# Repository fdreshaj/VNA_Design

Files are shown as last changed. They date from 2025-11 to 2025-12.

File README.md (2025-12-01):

# VNA_Design
Work in Progress Design of a VNA 

The Subsystems and Simulations folder contains all files related to the research and pre fabrication testing/simulations of subsystems

VNA_Project folder contains all KiCad files of the board itself. Specifically open VNA_Project.kicad_pro to check out the design. KiCad files do not have RF subsystem layout as that will be done in ADS during testing.

Motherboard Layout

Stackup:



3D+Layer View:

















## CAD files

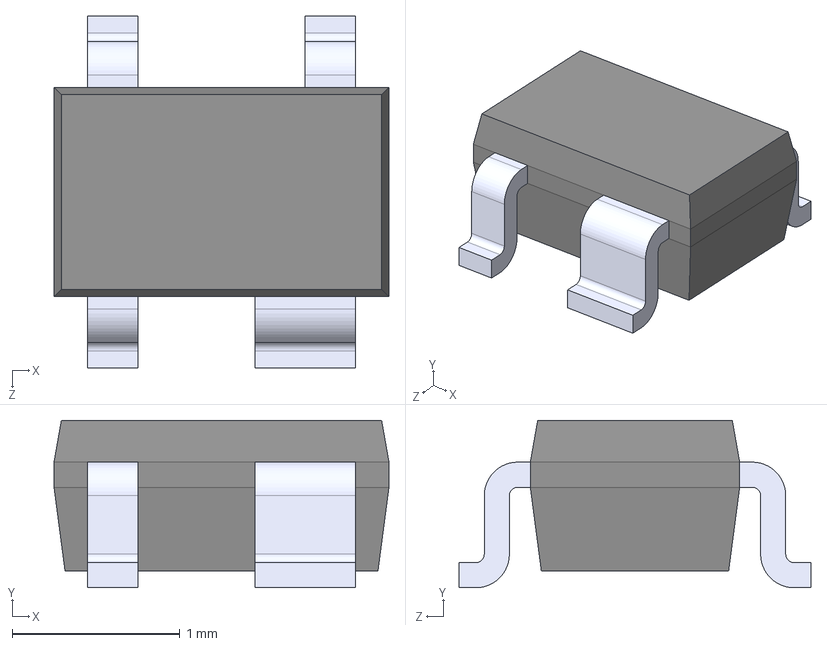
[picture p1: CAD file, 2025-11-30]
KiCad Symbols and Footprints/BFP620H7764XTSA1/BFP620H7764XTSA1.step
2.00 x 1.00 x 2.10 mm

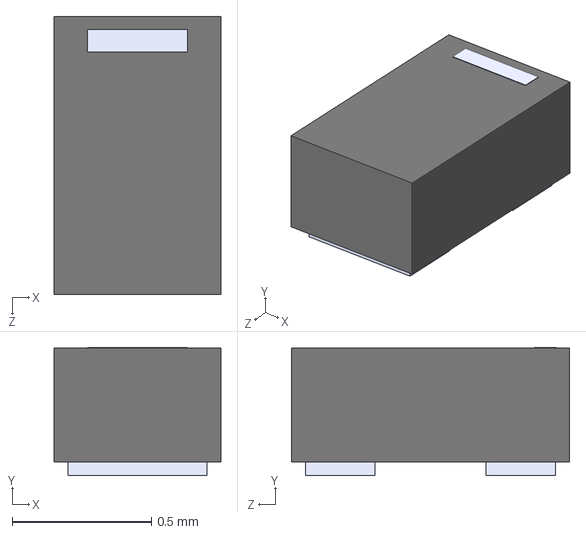
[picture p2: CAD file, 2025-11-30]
KiCad Symbols and Footprints/LIB_SMV1247-040LF/SMV1247-040LF/3D/SMV1247-040LF.stp
0.6 x 0.462 x 1.00 mm

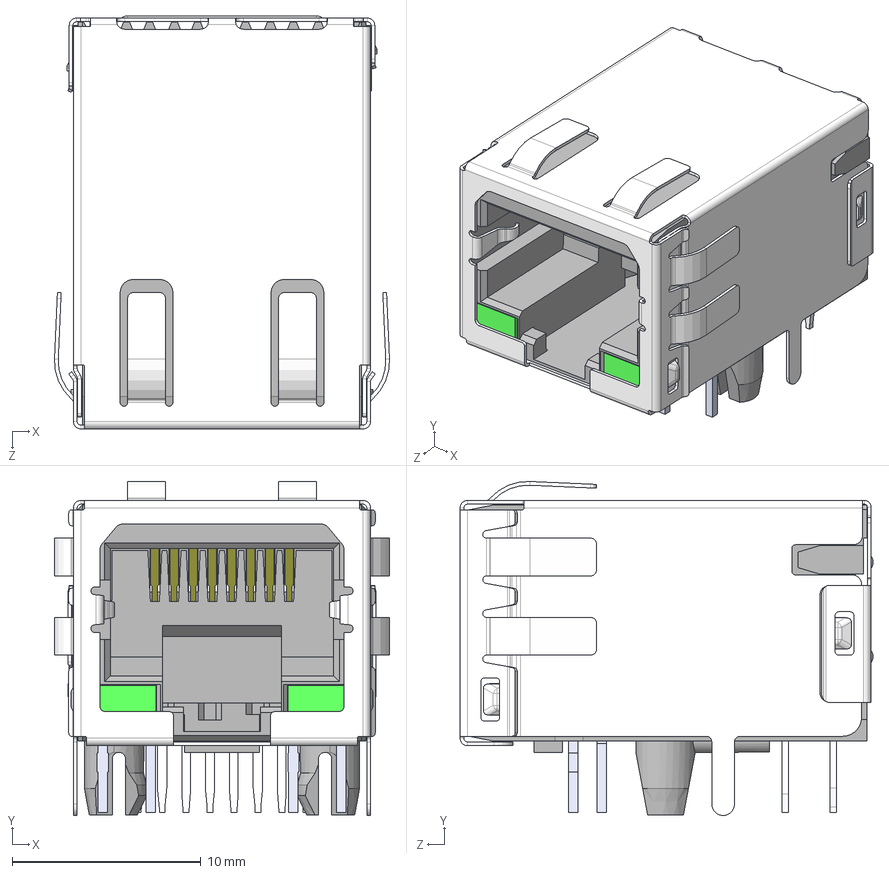
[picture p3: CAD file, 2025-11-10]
KiCad Symbols and Footprints/RJMG1BD3B8K1ANR.STEP
17.8 x 17.7 x 21.9 mm
R12-P120_C TYPE S11改善成本
R12-C130_成品 x 4
R12-C120_成品 x 4
R12-P110_R12-P110XACG-TYPE G 改善成本 斜腳燈，有鐵殼，LOCK腳
LED_LEFTｱﾗ_ x 2
R12-C310-2.20_成品
PCB_無鐵殼1G
S11-S110_ALL Spring1.0,R3.05,有燈，UDE LOGO

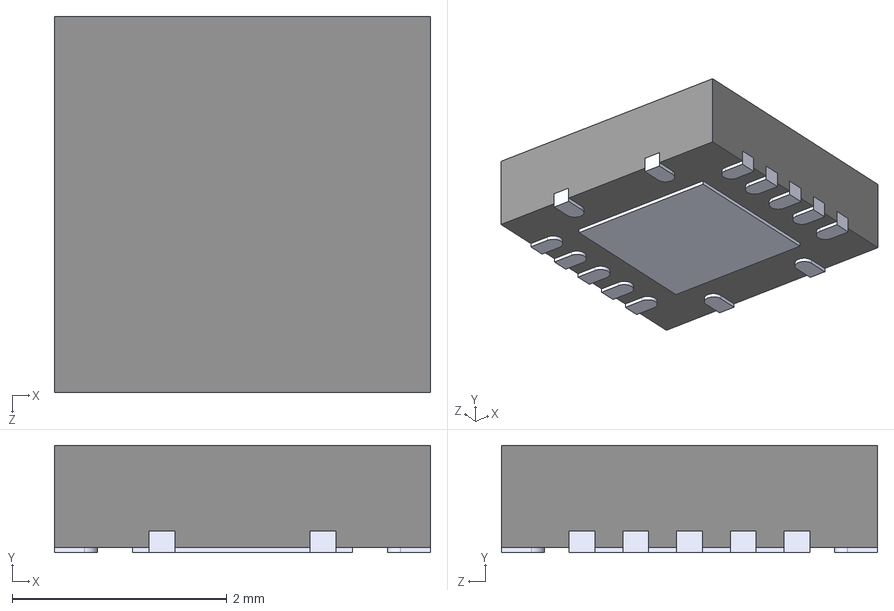
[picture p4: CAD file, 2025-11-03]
KiCad Symbols and Footprints/TPS54620RGYR/TPS54620RGYR.step
3.50 x 1.00 x 3.50 mm

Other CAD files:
KiCad Symbols and Footprints/LIB_SMV1247-040LF/SMV1247-040LF/Allegro/sms7630040lf.psm
KiCad Symbols and Footprints/LIB_SMV1247-040LF/SMV1247-040LF/DEHDL/smv1247_040lf/chips/chips.prt

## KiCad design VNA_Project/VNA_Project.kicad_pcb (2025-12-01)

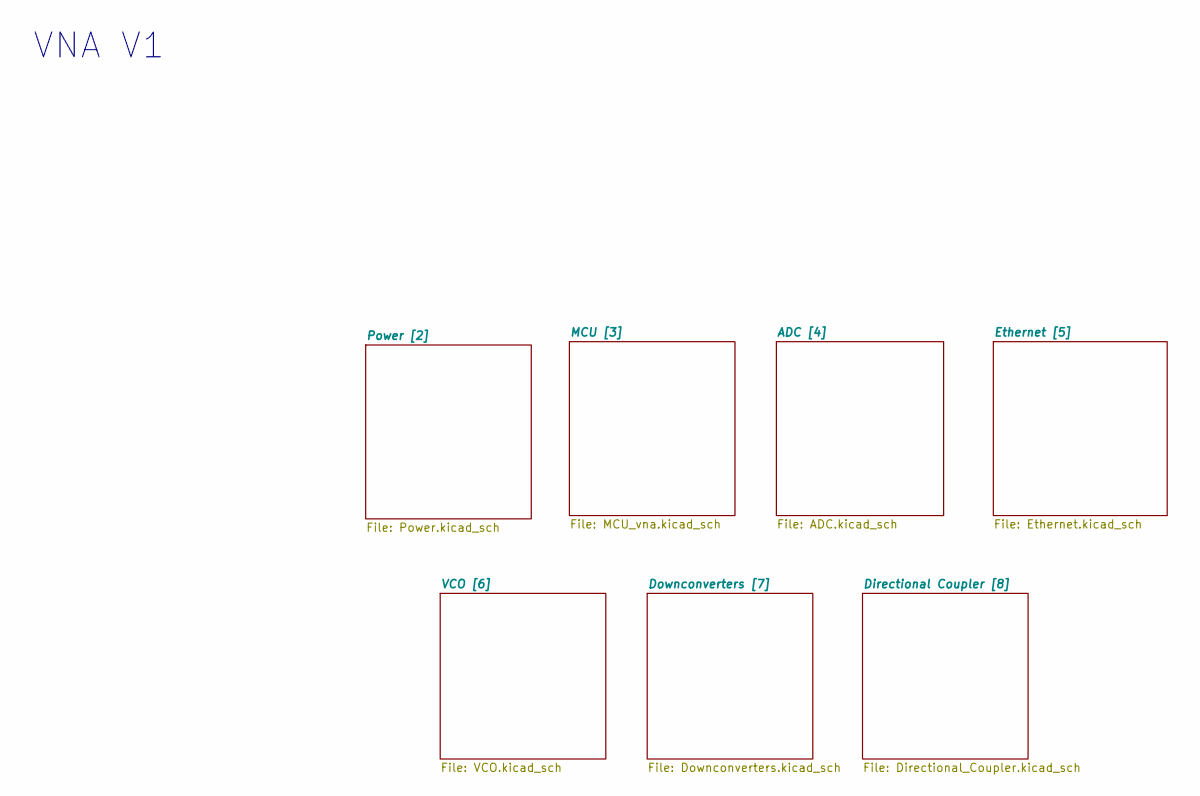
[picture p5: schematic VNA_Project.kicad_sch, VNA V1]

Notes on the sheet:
VNA V1

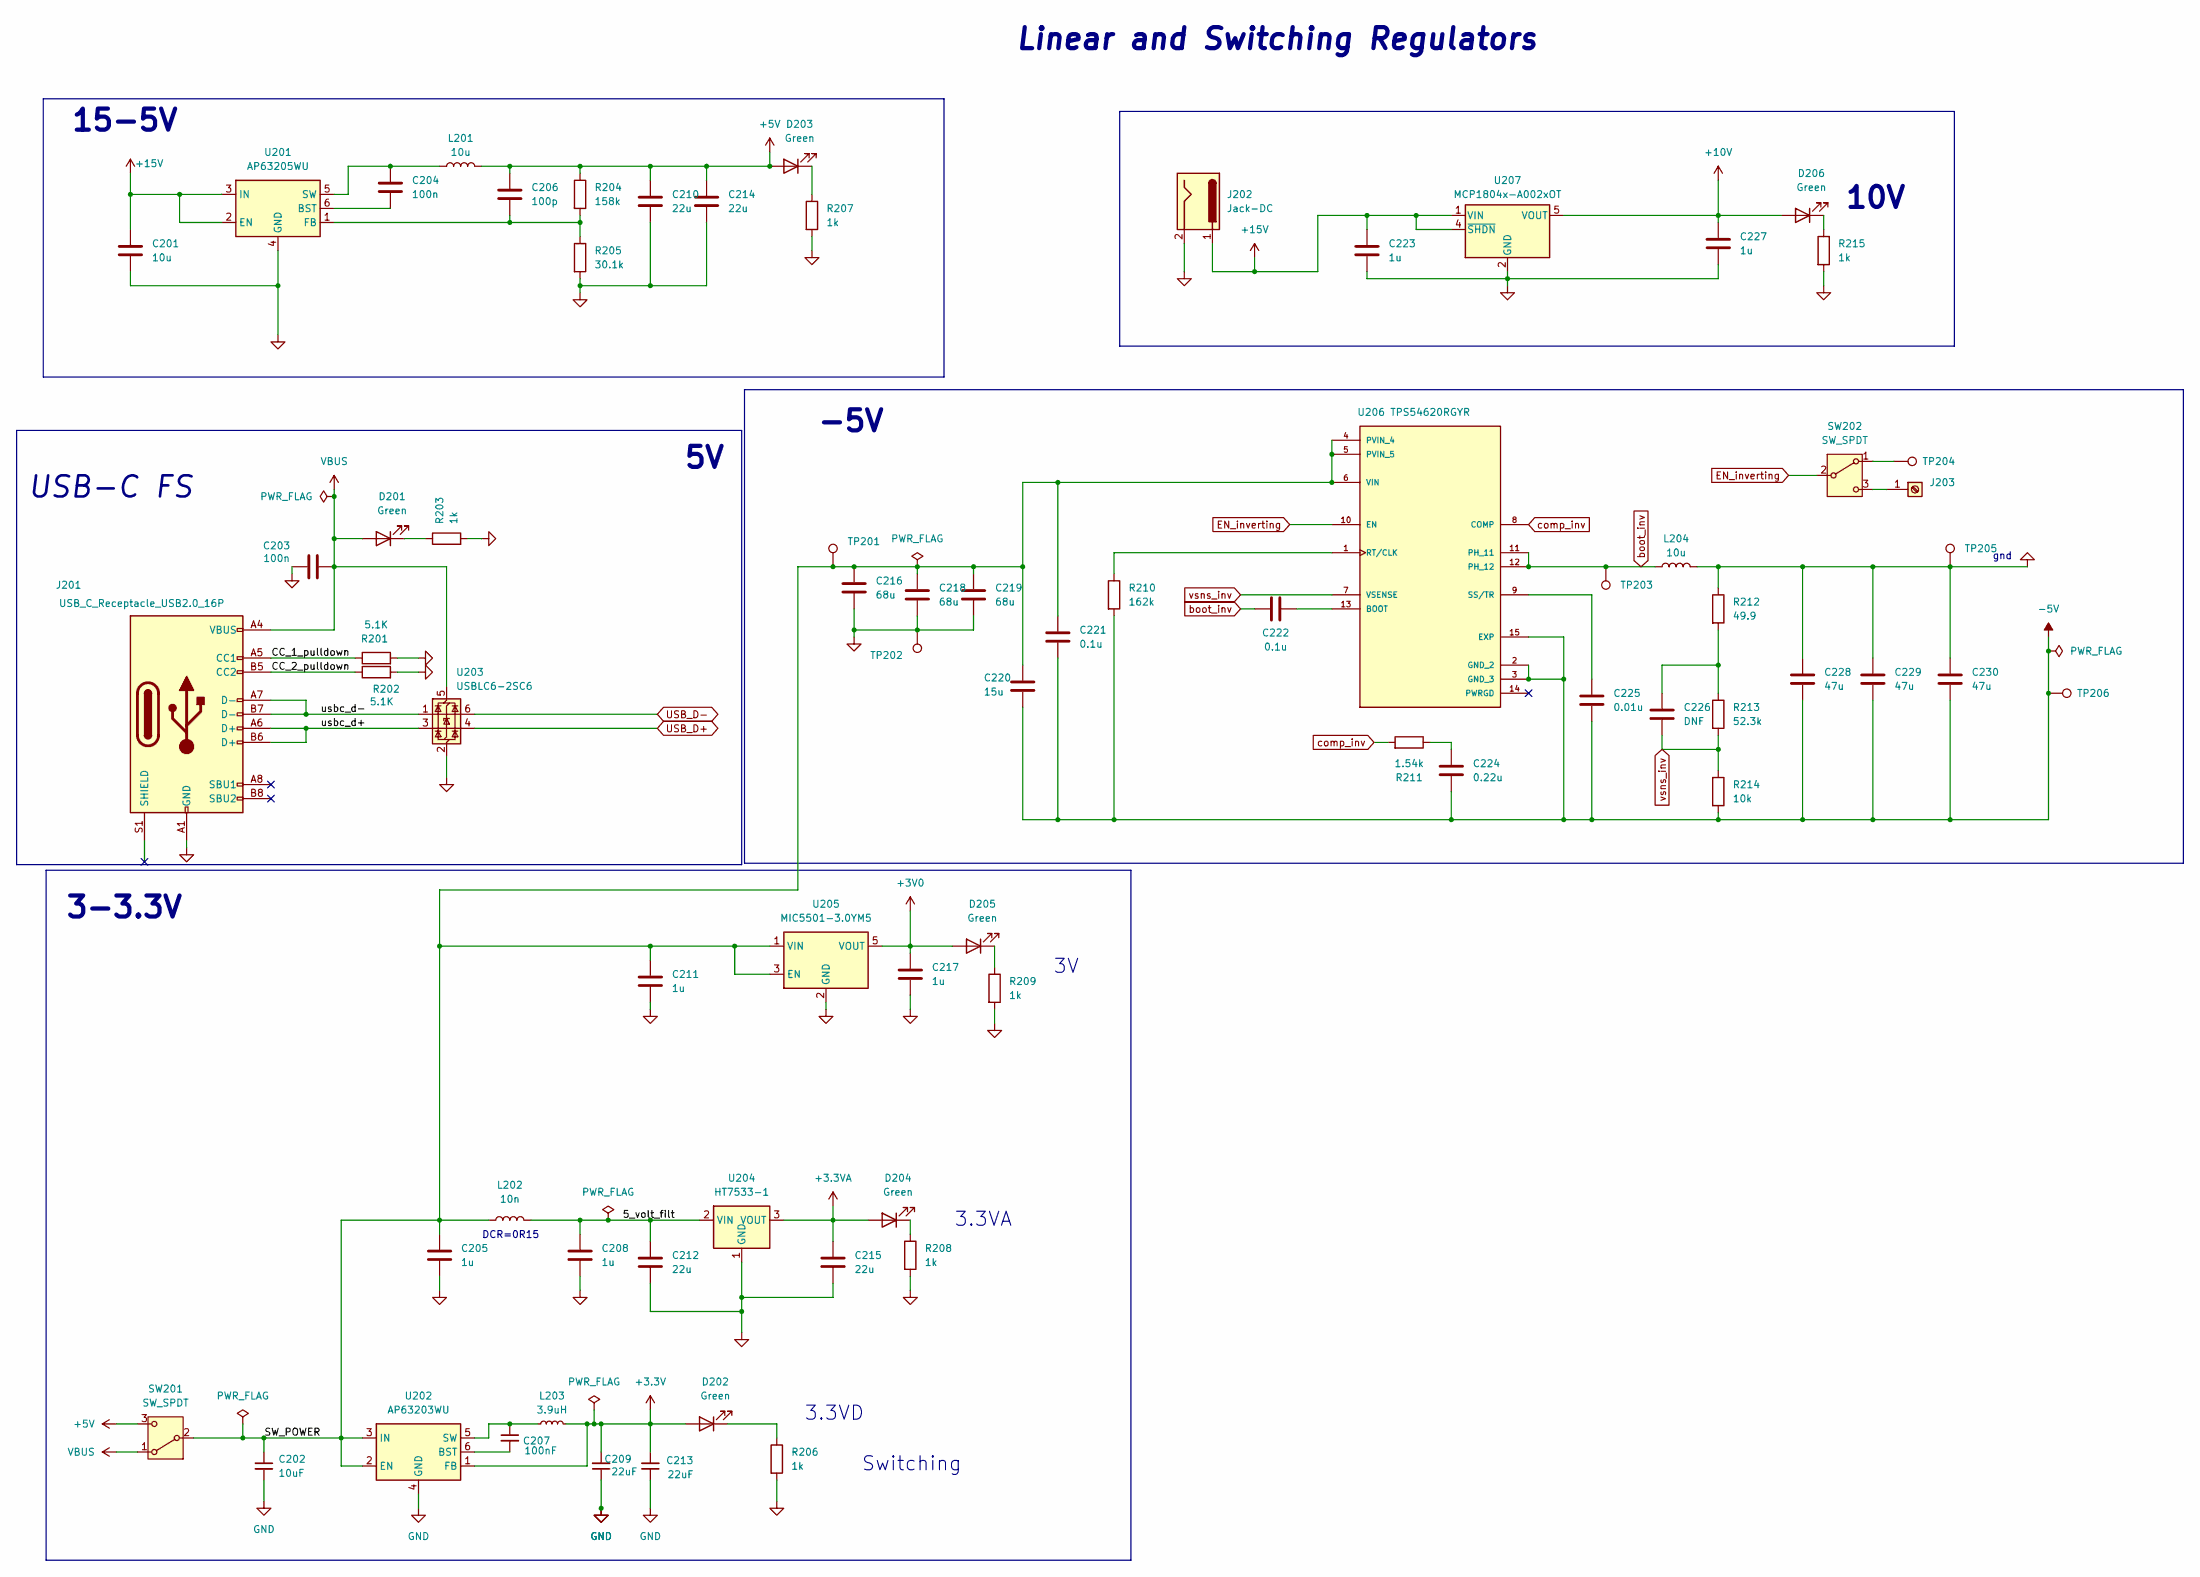
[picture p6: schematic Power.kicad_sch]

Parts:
C201: 10u; C_0805_2012Metric
C202: 10uF; C_0805_2012Metric
C203, C204: 100n; C_0603_1608Metric
C205, C208, C211, C217, C223, C227: 1u; C_0805_2012Metric
C206: 100p; C_0805_2012Metric
C207: 100nF; C_0603_1608Metric
C209, C213: 22uF; C_0805_2012Metric
C210, C212, C214, C215: 22u; C_0805_2012Metric
C216, C218, C219: 68u; C_0805_2012Metric
C220: 15u; C_0805_2012Metric
C221, C222: 0.1u; C_0603_1608Metric
C224: 0.22u; C_0805_2012Metric
C225: 0.01u; C_0805_2012Metric
C226: DNF; C_0805_2012Metric
C228, C229, C230: 47u; C_0805_2012Metric
D201, D202, D203, D204, D205, D206: Green; LED_0603_1608Metric_Pad1.05x0.95mm_HandSolder
J201: USB_C_Receptacle_USB2.0_16P; USB_C_Receptacle_G-Switch_GT-USB-7010ASV
J202: Jack-DC; BarrelJack_GCT_DCJ200-10-A_Horizontal
J203: Screw_Terminal_01x01; TerminalBlock_MaiXu_MX126-5.0-02P_1x02_P5.00mm
L201, L204: 10u; L_APV_ANR6020
L202: 10n; L_APV_ANR6020
L203: 3.9uH; L_APV_ANR6020
R201, R202: 5.1K; R_0603_1608Metric_Pad0.98x0.95mm_HandSolder
R203, R206, R207, R208, R209, R215: 1k; R_0603_1608Metric_Pad0.98x0.95mm_HandSolder
R204: 158k; R_0603_1608Metric_Pad0.98x0.95mm_HandSolder
R205: 30.1k; R_0603_1608Metric_Pad0.98x0.95mm_HandSolder
R210: 162k; R_0603_1608Metric_Pad0.98x0.95mm_HandSolder
R211: 1.54k; R_0603_1608Metric_Pad0.98x0.95mm_HandSolder
R212: 49.9; R_0603_1608Metric_Pad0.98x0.95mm_HandSolder
R213: 52.3k; R_0603_1608Metric_Pad0.98x0.95mm_HandSolder
R214: 10k; R_0603_1608Metric_Pad0.98x0.95mm_HandSolder
SW201, SW202: SW_SPDT; SW_Slide_SPDT_Straight_CK_OS102011MS2Q
TP201, TP202, TP203, TP204, TP205, TP206: TestPoint; TestPoint_Pad_D4.0mm
U201: AP63205WU; TSOT-23-6_HandSoldering
U202: AP63203WU; TSOT-23-6_HandSoldering
U203: USBLC6-2SC6; SOT-23-6_Handsoldering
U204: HT7533-1; SOT-89-3_Handsoldering
U205: MIC5501-3.0YM5; SOT-23-5_HandSoldering
U206: TPS54620RGYR; PARTREV 06/2011
U207: MCP1804x-A002xOT; SOT-23-5_HandSoldering

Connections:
+3.3V: C209.2, C213.2, D202.2 (A), L203.2, U202.1 (FB); also elsewhere on the board
+3.3VA: C215.1, D204.2 (A), U204.3 (VOUT); also elsewhere on the board
+3V0: C217.1, D205.2 (A), U205.5 (VOUT); also elsewhere on the board
+5V: C206.1, C210.1, C214.1, D203.2 (A), L201.2, R204.1, SW201.3 (C); also elsewhere on the board
+10V: C227.1, D206.2 (A), U207.5 (VOUT); also elsewhere on the board
+15V: C201.1, C223.1, J202.1, U201.2 (EN), U201.3 (IN), U207.1 (VIN), U207.4 (~SHDN)
-5V: C220.2, C221.2, C224.2, C225.2, C228.2, C229.2, C230.2, R210.2, R214.2, TP206.1, U206.2 (GND_2), U206.3 (GND_3), U206.15 (EXP); also elsewhere on the board
/Power [2]/5_volt_filt: C208.1, C212.1, L202.2, U204.2 (VIN)
/Power [2]/CC_1_pulldown: J201.A5 (CC1), R201.1
/Power [2]/CC_2_pulldown: J201.B5 (CC2), R202.1
/Power [2]/SW_POWER: C202.1, C205.1, C211.1, C216.1, C218.1, C219.1, C220.1, C221.1, L202.1, SW201.2 (B), TP201.1, U202.2 (EN), U202.3 (IN), U205.1 (VIN), U205.3 (EN), U206.4 (PVIN_4), U206.5 (PVIN_5), U206.6 (VIN)
/Power [2]/usbc_d+: J201.A6 (D+), J201.B6 (D+), U203.3 (I/O2)
/Power [2]/usbc_d-: J201.A7 (D-), J201.B7 (D-), U203.1 (I/O1)
EN_inverting: SW202.2 (B), U206.10 (EN)
GND: C201.2, C202.2, C203.1, C205.2, C208.2, C209.1, C210.2, C211.2, C212.2, C213.1, C214.2, C215.2, C216.2, C217.2, C218.2, C219.2, C223.2, C227.2, C228.1, C229.1, C230.1, J201.A1 (GND), J201.A12 (GND), J201.B1 (GND), J201.B12 (GND), J202.2, L204.2, R201.2, R202.2, R203.2, R205.2, R206.2, R207.2, R208.2, R209.2, R212.1, R215.2, TP202.1, TP205.1, U201.4 (GND), U202.4 (GND), U203.2 (GND), U204.1 (GND), U205.2 (GND), U207.2 (GND); also elsewhere on the board
unnamed: C224.1, R211.1
unnamed: C226.1, R212.2, R213.1
unnamed: D201.1 (K), R203.1
unnamed: D202.1 (K), R206.1
unnamed: D203.1 (K), R207.1
unnamed: D204.1 (K), R208.1
unnamed: D205.1 (K), R209.1
unnamed: D206.1 (K), R215.1
unnamed: J203.1, SW202.3 (C)
unnamed: SW202.1 (A), TP204.1
unnamed: C204.2, U201.6 (BST)
unnamed: C206.2, R204.2, R205.1, U201.1 (FB)
unnamed: C204.1, L201.1, U201.5 (SW)
unnamed: C207.2, U202.6 (BST)
unnamed: C207.1, L203.1, U202.5 (SW)
unnamed: C222.2, U206.13 (BOOT)
unnamed: R210.1, U206.1 (RT/CLK)
unnamed: C225.1, U206.9 (SS/TR)
USB_D+: U203.4 (I/O2); also elsewhere on the board
USB_D-: U203.6 (I/O1); also elsewhere on the board
VBUS: C203.2, D201.2 (A), J201.A4 (VBUS), J201.A9 (VBUS), J201.B4 (VBUS), J201.B9 (VBUS), SW201.1 (A), U203.5 (VBUS)
boot_inv: C222.1, L204.1, TP203.1, U206.11 (PH_11), U206.12 (PH_12)
comp_inv: R211.2, U206.8 (COMP)
vsns_inv: C226.2, R213.2, R214.1, U206.7 (VSENSE)

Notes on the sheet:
Switching
DCR=0R15
Linear and Switching Regulators
3.3VD
gnd
10V
3.3VA
-5V
3-3.3V
15-5V
USB-C FS

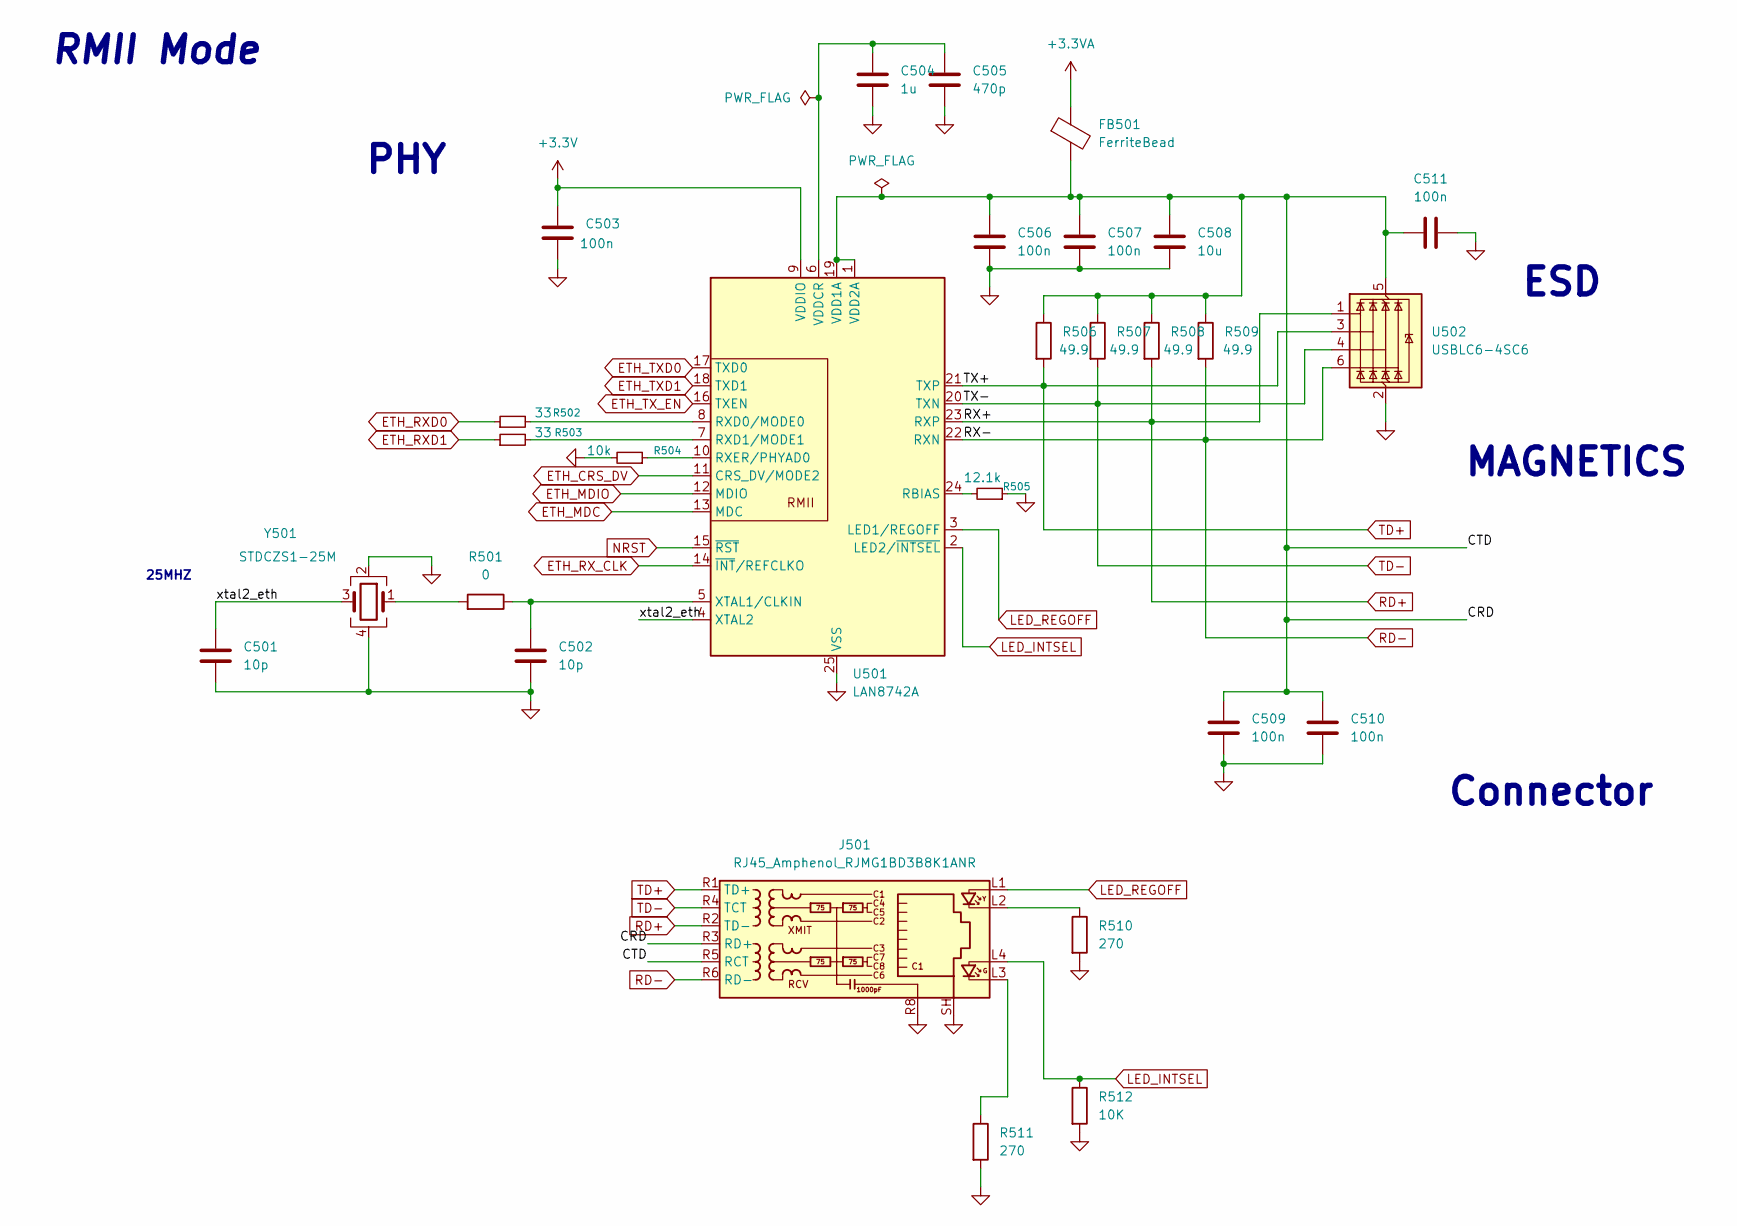
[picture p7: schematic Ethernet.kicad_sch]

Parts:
C501, C502: 10p; C_0603_1608Metric_Pad1.08x0.95mm_HandSolder
C503, C506, C507, C509, C510, C511: 100n; C_0603_1608Metric_Pad1.08x0.95mm_HandSolder
C504: 1u; C_0603_1608Metric_Pad1.08x0.95mm_HandSolder
C505: 470p; C_0603_1608Metric_Pad1.08x0.95mm_HandSolder
C508: 10u; C_0603_1608Metric_Pad1.08x0.95mm_HandSolder
FB501: FerriteBead; L_0603_1608Metric_Pad1.05x0.95mm_HandSolder
J501: RJ45_Amphenol_RJMG1BD3B8K1ANR
R501: 0; R_0603_1608Metric_Pad0.98x0.95mm_HandSolder
R502, R503: 33; R_0603_1608Metric_Pad0.98x0.95mm_HandSolder
R504: 10k; R_0603_1608Metric_Pad0.98x0.95mm_HandSolder
R505: 12.1k; R_0603_1608Metric_Pad0.98x0.95mm_HandSolder
R506, R507, R508, R509: 49.9; R_0603_1608Metric_Pad0.98x0.95mm_HandSolder
R510, R511: 270; R_0603_1608Metric_Pad0.98x0.95mm_HandSolder
R512: 10K; R_0603_1608Metric_Pad0.98x0.95mm_HandSolder
U501: LAN8742A; VQFN-24-1EP_4x4mm_P0.5mm_EP2.5x2.5mm
U502: USBLC6-4SC6; SOT-23-6_Handsoldering
Y501: STDCZS1-25M; Crystal_SMD_2016-4Pin_2.0x1.6mm

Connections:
+3.3V: C503.1, U501.9 (VDDIO); also elsewhere on the board
+3.3VA: FB501.1; also elsewhere on the board
/Ethernet [5]/CRD: C506.1, C507.1, C508.1, C509.1, C510.1, C511.1, FB501.2, J501.R3 (RD+), J501.R5 (RCT), R506.1, R507.1, R508.1, R509.1, U501.1 (VDD2A), U501.19 (VDD1A), U502.5 (VBUS)
/Ethernet [5]/xtal2_eth: C501.1, U501.4 (XTAL2), Y501.3
ETH_CRS_DV: U501.11 (CRS_DV/MODE2); also elsewhere on the board
ETH_MDC: U501.13 (MDC); also elsewhere on the board
ETH_MDIO: U501.12 (MDIO); also elsewhere on the board
ETH_RXD0: R502.1; also elsewhere on the board
ETH_RXD1: R503.1; also elsewhere on the board
ETH_RX_CLK: U501.14 (~INT/REFCLKO); also elsewhere on the board
ETH_TXD0: U501.17 (TXD0); also elsewhere on the board
ETH_TXD1: U501.18 (TXD1); also elsewhere on the board
ETH_TX_EN: U501.16 (TXEN); also elsewhere on the board
GND: C501.2, C502.2, C503.2, C504.2, C505.2, C506.2, C507.2, C508.2, C509.2, C510.2, C511.2, J501.R8, J501.SH, R504.2, R505.1, R510.2, R511.2, R512.2, U501.25 (VSS), U502.2 (GND), Y501.2, Y501.4; also elsewhere on the board
LED_INTSEL: J501.L4, R512.1, U501.2 (LED2/~INTSEL)
LED_REGOFF: J501.L1, U501.3 (LED1/REGOFF)
NRST: U501.15 (~RST); also elsewhere on the board
unnamed: J501.L2, R510.1
unnamed: J501.L3, R511.1
unnamed: R501.2, Y501.1
unnamed: R505.2, U501.24 (RBIAS)
unnamed: R502.2, U501.8 (RXD0/MODE0)
unnamed: R503.2, U501.7 (RXD1/MODE1)
unnamed: R504.1, U501.10 (RXER/PHYAD0)
unnamed: C504.1, C505.1, U501.6 (VDDCR)
unnamed: C502.1, R501.1, U501.5 (XTAL1/CLKIN)
RD+: J501.R2 (TD-), R508.2, U501.23 (RXP), U502.1 (I/O1)
RD-: J501.R6 (RD-), R509.2, U501.22 (RXN), U502.6 (I/O4)
TD+: J501.R1 (TD+), R506.2, U501.21 (TXP), U502.3 (I/O2)
TD-: J501.R4 (TCT), R507.2, U501.20 (TXN), U502.4 (I/O3)

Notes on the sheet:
MAGNETICS
Connector
25MHZ
RMII Mode
ESD
PHY

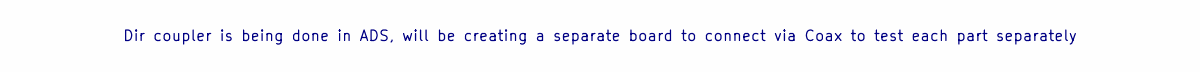
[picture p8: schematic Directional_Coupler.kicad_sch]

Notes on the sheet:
Dir coupler is being done in ADS, will be creating a separate board to connect via Coax to test each part separately

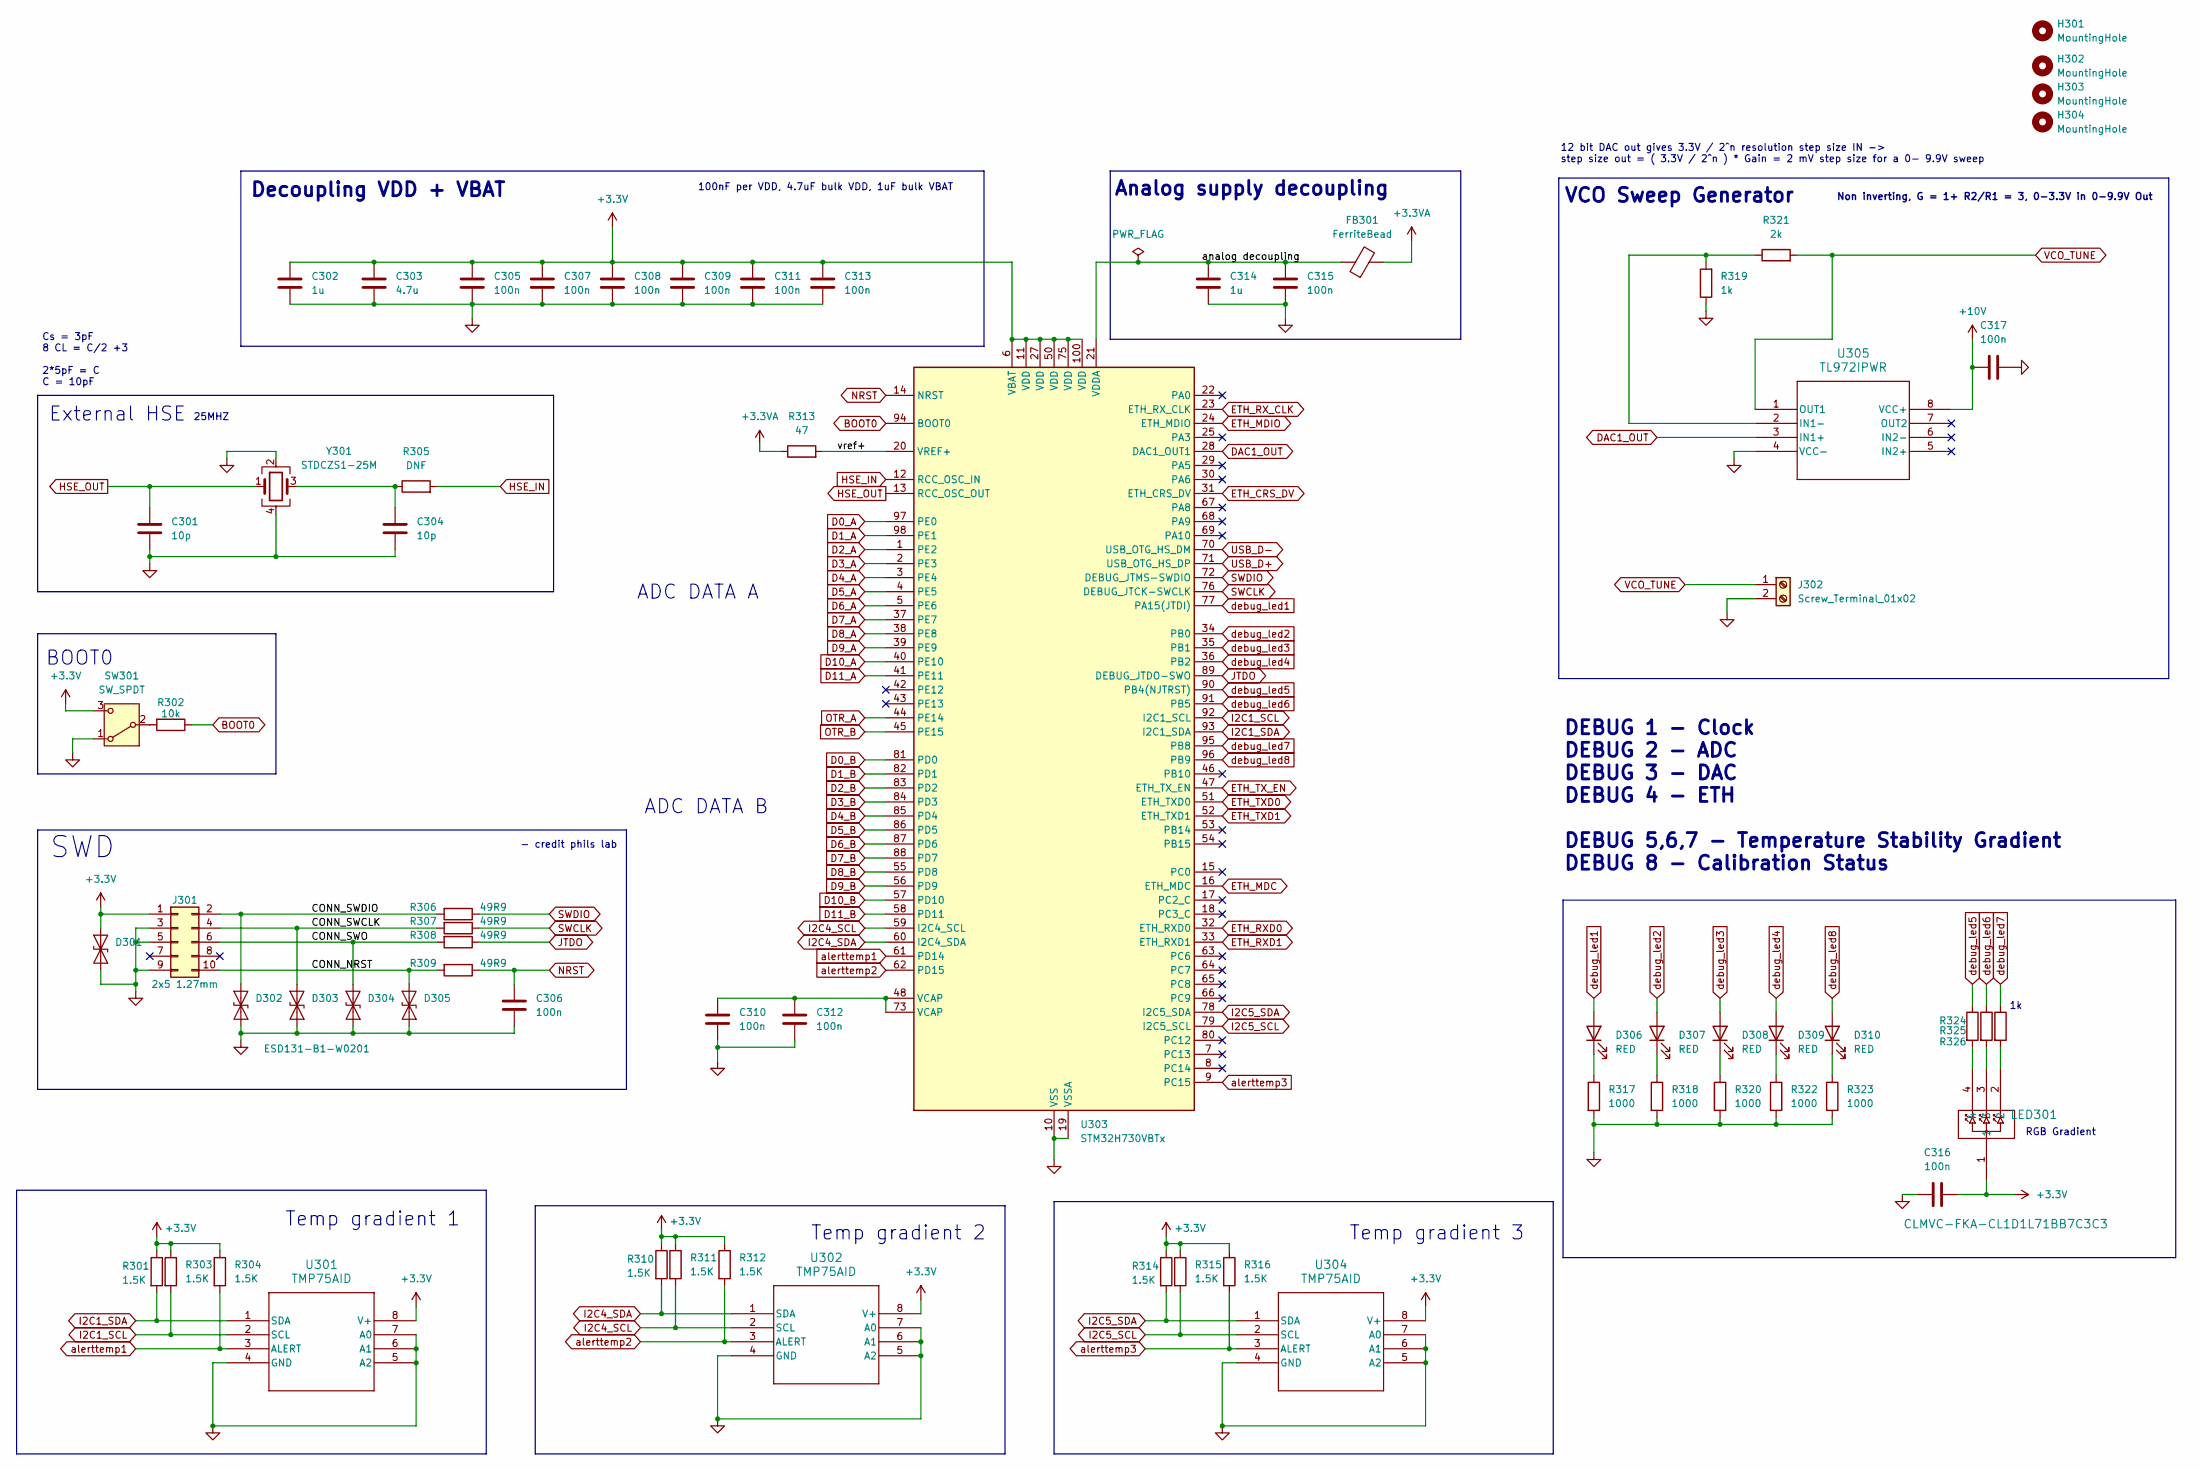
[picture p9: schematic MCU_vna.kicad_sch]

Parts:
C301, C304: 10p; C_0603_1608Metric_Pad1.08x0.95mm_HandSolder
C302, C314: 1u; C_0603_1608Metric_Pad1.08x0.95mm_HandSolder
C303: 4.7u; C_0603_1608Metric_Pad1.08x0.95mm_HandSolder
C305, C306, C307, C308, C309, C310, C311, C312, C313, C315, C316, C317: 100n; C_0603_1608Metric_Pad1.08x0.95mm_HandSolder
D301, D302, D303, D304, D305: ESD131-B1-W0201; Nexperia_DSN0603-2_0.6x0.3mm_P0.4mm
D306, D307, D308, D309, D310: RED; LED_0603_1608Metric_Pad1.05x0.95mm_HandSolder
FB301: FerriteBead; L_0603_1608Metric_Pad1.05x0.95mm_HandSolder
H301, H302, H303, H304: MountingHole; MountingHole_2.2mm_M2
J301: 2x5 1.27mm; PinHeader_2x05_P2.54mm_Vertical
J302: Screw_Terminal_01x02; TerminalBlock_MaiXu_MX126-5.0-02P_1x02_P5.00mm
LED301: CLMVC-FKA-CL1D1L71BB7C3C3; CLMVC-FKA-CL1D1L71BB7C3C3_CRE
R301, R303, R304, R310, R311, R312, R314, R315, R316: 1.5K; R_0603_1608Metric_Pad0.98x0.95mm_HandSolder
R302: 10k; R_0603_1608Metric_Pad0.98x0.95mm_HandSolder
R305: DNF; R_0603_1608Metric_Pad0.98x0.95mm_HandSolder
R306, R307, R308, R309: 49R9; R_0603_1608Metric_Pad0.98x0.95mm_HandSolder
R313: 47; R_0603_1608Metric_Pad0.98x0.95mm_HandSolder
R317, R318, R320, R322, R323, R324, R325, R326: 1000; R_0603_1608Metric_Pad0.98x0.95mm_HandSolder
R319: 1k; R_0603_1608Metric_Pad0.98x0.95mm_HandSolder
R321: 2k; R_0603_1608Metric_Pad0.98x0.95mm_HandSolder
SW301: SW_SPDT; SW_Slide_SPDT_Straight_CK_OS102011MS2Q
U301, U302, U304: TMP75AID
U303: STM32H730VBTx; LQFP-100_14x14mm_P0.5mm
U305: TL972IPWR
Y301: STDCZS1-25M; Crystal_SMD_2016-4Pin_2.0x1.6mm

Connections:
+3.3V: C302.1, C303.1, C305.1, C307.1, C308.1, C309.1, C311.1, C313.1, C316.1, D301.2 (A2), J301.1, LED301.1, R301.1, R303.1, R304.1, R310.1, R311.1, R312.1, R314.1, R315.1, R316.1, SW301.3 (C), U301.8 (V+), U302.8 (V+), U303.6 (VBAT), U303.11 (VDD), U303.27 (VDD), U303.50 (VDD), U303.75 (VDD), U303.100 (VDD), U304.8 (V+); also elsewhere on the board
+3.3VA: FB301.2, R313.1; also elsewhere on the board
+10V: C317.1, U305.8 (VCC+); also elsewhere on the board
/MCU [3]/CONN_NRST: D305.2 (A2), J301.10, R309.2
/MCU [3]/CONN_SWCLK: D303.2 (A2), J301.4, R307.2
/MCU [3]/CONN_SWDIO: D302.2 (A2), J301.2, R306.2
/MCU [3]/CONN_SWO: D304.2 (A2), J301.6, R308.2
/MCU [3]/analog decoupling: C314.1, C315.1, FB301.1, U303.21 (VDDA)
/MCU [3]/vref+: R313.2, U303.20 (VREF+)
BOOT0: R302.1, U303.94 (BOOT0)
D0_A: U303.97 (PE0); also elsewhere on the board
D0_B: U303.81 (PD0); also elsewhere on the board
D1_A: U303.98 (PE1); also elsewhere on the board
D1_B: U303.82 (PD1); also elsewhere on the board
D2_A: U303.1 (PE2); also elsewhere on the board
D2_B: U303.83 (PD2); also elsewhere on the board
D3_A: U303.2 (PE3); also elsewhere on the board
D3_B: U303.84 (PD3); also elsewhere on the board
D4_A: U303.3 (PE4); also elsewhere on the board
D4_B: U303.85 (PD4); also elsewhere on the board
D5_A: U303.4 (PE5); also elsewhere on the board
D5_B: U303.86 (PD5); also elsewhere on the board
D6_A: U303.5 (PE6); also elsewhere on the board
D6_B: U303.87 (PD6); also elsewhere on the board
D7_A: U303.37 (PE7); also elsewhere on the board
D7_B: U303.88 (PD7); also elsewhere on the board
D8_A: U303.38 (PE8); also elsewhere on the board
D8_B: U303.55 (PD8); also elsewhere on the board
D9_A: U303.39 (PE9); also elsewhere on the board
D9_B: U303.56 (PD9); also elsewhere on the board
D10_A: U303.40 (PE10); also elsewhere on the board
D10_B: U303.57 (PD10); also elsewhere on the board
D11_A: U303.41 (PE11); also elsewhere on the board
D11_B: U303.58 (PD11); also elsewhere on the board
DAC1_OUT: U303.28 (DAC1_OUT1), U305.3 (IN1+)
ETH_CRS_DV: U303.31 (ETH_CRS_DV); also elsewhere on the board
ETH_MDC: U303.16 (ETH_MDC); also elsewhere on the board
ETH_MDIO: U303.24 (ETH_MDIO); also elsewhere on the board
ETH_RXD0: U303.32 (ETH_RXD0); also elsewhere on the board
ETH_RXD1: U303.33 (ETH_RXD1); also elsewhere on the board
ETH_RX_CLK: U303.23 (ETH_RX_CLK); also elsewhere on the board
ETH_TXD0: U303.51 (ETH_TXD0); also elsewhere on the board
ETH_TXD1: U303.52 (ETH_TXD1); also elsewhere on the board
ETH_TX_EN: U303.47 (ETH_TX_EN); also elsewhere on the board
GND: C301.2, C302.2, C303.2, C304.2, C305.2, C306.2, C307.2, C308.2, C309.2, C310.2, C311.2, C312.2, C313.2, C314.2, C315.2, C316.2, C317.2, D301.1 (A1), D302.1 (A1), D303.1 (A1), D304.1 (A1), D305.1 (A1), J301.3, J301.5, J301.9, J302.2, R317.2, R318.2, R319.1, R320.2, R322.2, R323.2, SW301.1 (A), U301.4 (GND), U301.5 (A2), U301.6 (A1), U301.7 (A0), U302.4 (GND), U302.5 (A2), U302.6 (A1), U302.7 (A0), U303.10 (VSS), U303.19 (VSSA), U303.26 (VSS), U303.49 (VSS), U303.74 (VSS), U303.99 (VSS), U304.4 (GND), U304.5 (A2), U304.6 (A1), U304.7 (A0), U305.4 (VCC-), Y301.2, Y301.4; also elsewhere on the board
HSE_IN: R305.2, U303.12 (RCC_OSC_IN)
HSE_OUT: C301.1, U303.13 (RCC_OSC_OUT), Y301.1
I2C1_SCL: R303.2, U301.2 (SCL), U303.92 (I2C1_SCL)
I2C1_SDA: R301.2, U301.1 (SDA), U303.93 (I2C1_SDA)
I2C4_SCL: R311.2, U302.2 (SCL), U303.59 (I2C4_SCL)
I2C4_SDA: R310.2, U302.1 (SDA), U303.60 (I2C4_SDA)
I2C5_SCL: R315.2, U303.79 (I2C5_SCL), U304.2 (SCL)
I2C5_SDA: R314.2, U303.78 (I2C5_SDA), U304.1 (SDA)
JTDO: R308.1, U303.89 (DEBUG_JTDO-SWO)
NRST: C306.1, R309.1, U303.14 (NRST); also elsewhere on the board
unnamed: C304.1, R305.1, Y301.3
unnamed: C310.1, C312.1, U303.48 (VCAP), U303.73 (VCAP)
unnamed: D306.1 (K), R317.1
unnamed: D307.1 (K), R318.1
unnamed: D308.1 (K), R320.1
unnamed: D309.1 (K), R322.1
unnamed: D310.1 (K), R323.1
unnamed: LED301.2, R326.2
unnamed: LED301.3, R325.2
unnamed: LED301.4, R324.2
unnamed: R302.2, SW301.2 (B)
unnamed: R319.2, R321.1, U305.2 (IN1-)
OTR_A: U303.44 (PE14); also elsewhere on the board
OTR_B: U303.45 (PE15); also elsewhere on the board
SWCLK: R307.1, U303.76 (DEBUG_JTCK-SWCLK)
SWDIO: R306.1, U303.72 (DEBUG_JTMS-SWDIO)
USB_D+: U303.71 (USB_OTG_HS_DP); also elsewhere on the board
USB_D-: U303.70 (USB_OTG_HS_DM); also elsewhere on the board
VCO_TUNE: J302.1, R321.2, U305.1 (OUT1)
alerttemp1: R304.2, U301.3 (ALERT), U303.61 (PD14)
alerttemp2: R312.2, U302.3 (ALERT), U303.62 (PD15)
alerttemp3: R316.2, U303.9 (PC15), U304.3 (ALERT)
debug_led1: D306.2 (A), U303.77 (PA15(JTDI))
debug_led2: D307.2 (A), U303.34 (PB0)
debug_led3: D308.2 (A), U303.35 (PB1)
debug_led4: D309.2 (A), U303.36 (PB2)
debug_led5: R324.1, U303.90 (PB4(NJTRST))
debug_led6: R325.1, U303.91 (PB5)
debug_led7: R326.1, U303.95 (PB8)
debug_led8: D310.2 (A), U303.96 (PB9)

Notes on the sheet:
Temp gradient 1
VCO Sweep Generator
100nF per VDD, 4.7uF bulk VDD, 1uF bulk VBAT
- credit phils lab
RGB Gradient
BOOT0
External HSE
Temp gradient 2
ADC DATA A
DEBUG 1 - Clock DEBUG 2 - ADC DEBUG 3 - DAC DEBUG 4 - ETH DEBUG 5,6,7 - Temperature Stability Gradient DEBUG 8 - Calibration Status
Analog supply decoupling
12 bit DAC out gives 3.3V / 2^n resolution step size IN -> step size out = ( 3.3V / 2^n ) * Gain = 2 mV step size for a 0- 9.9V sweep
Cs = 3pF 8 CL = C/2 +3 2*5pF = C C = 10pF
Decoupling VDD + VBAT
Temp gradient 3
Non inverting, G = 1+ R2/R1 = 3, 0-3.3V in 0-9.9V Out
ADC DATA B
25MHZ
SWD

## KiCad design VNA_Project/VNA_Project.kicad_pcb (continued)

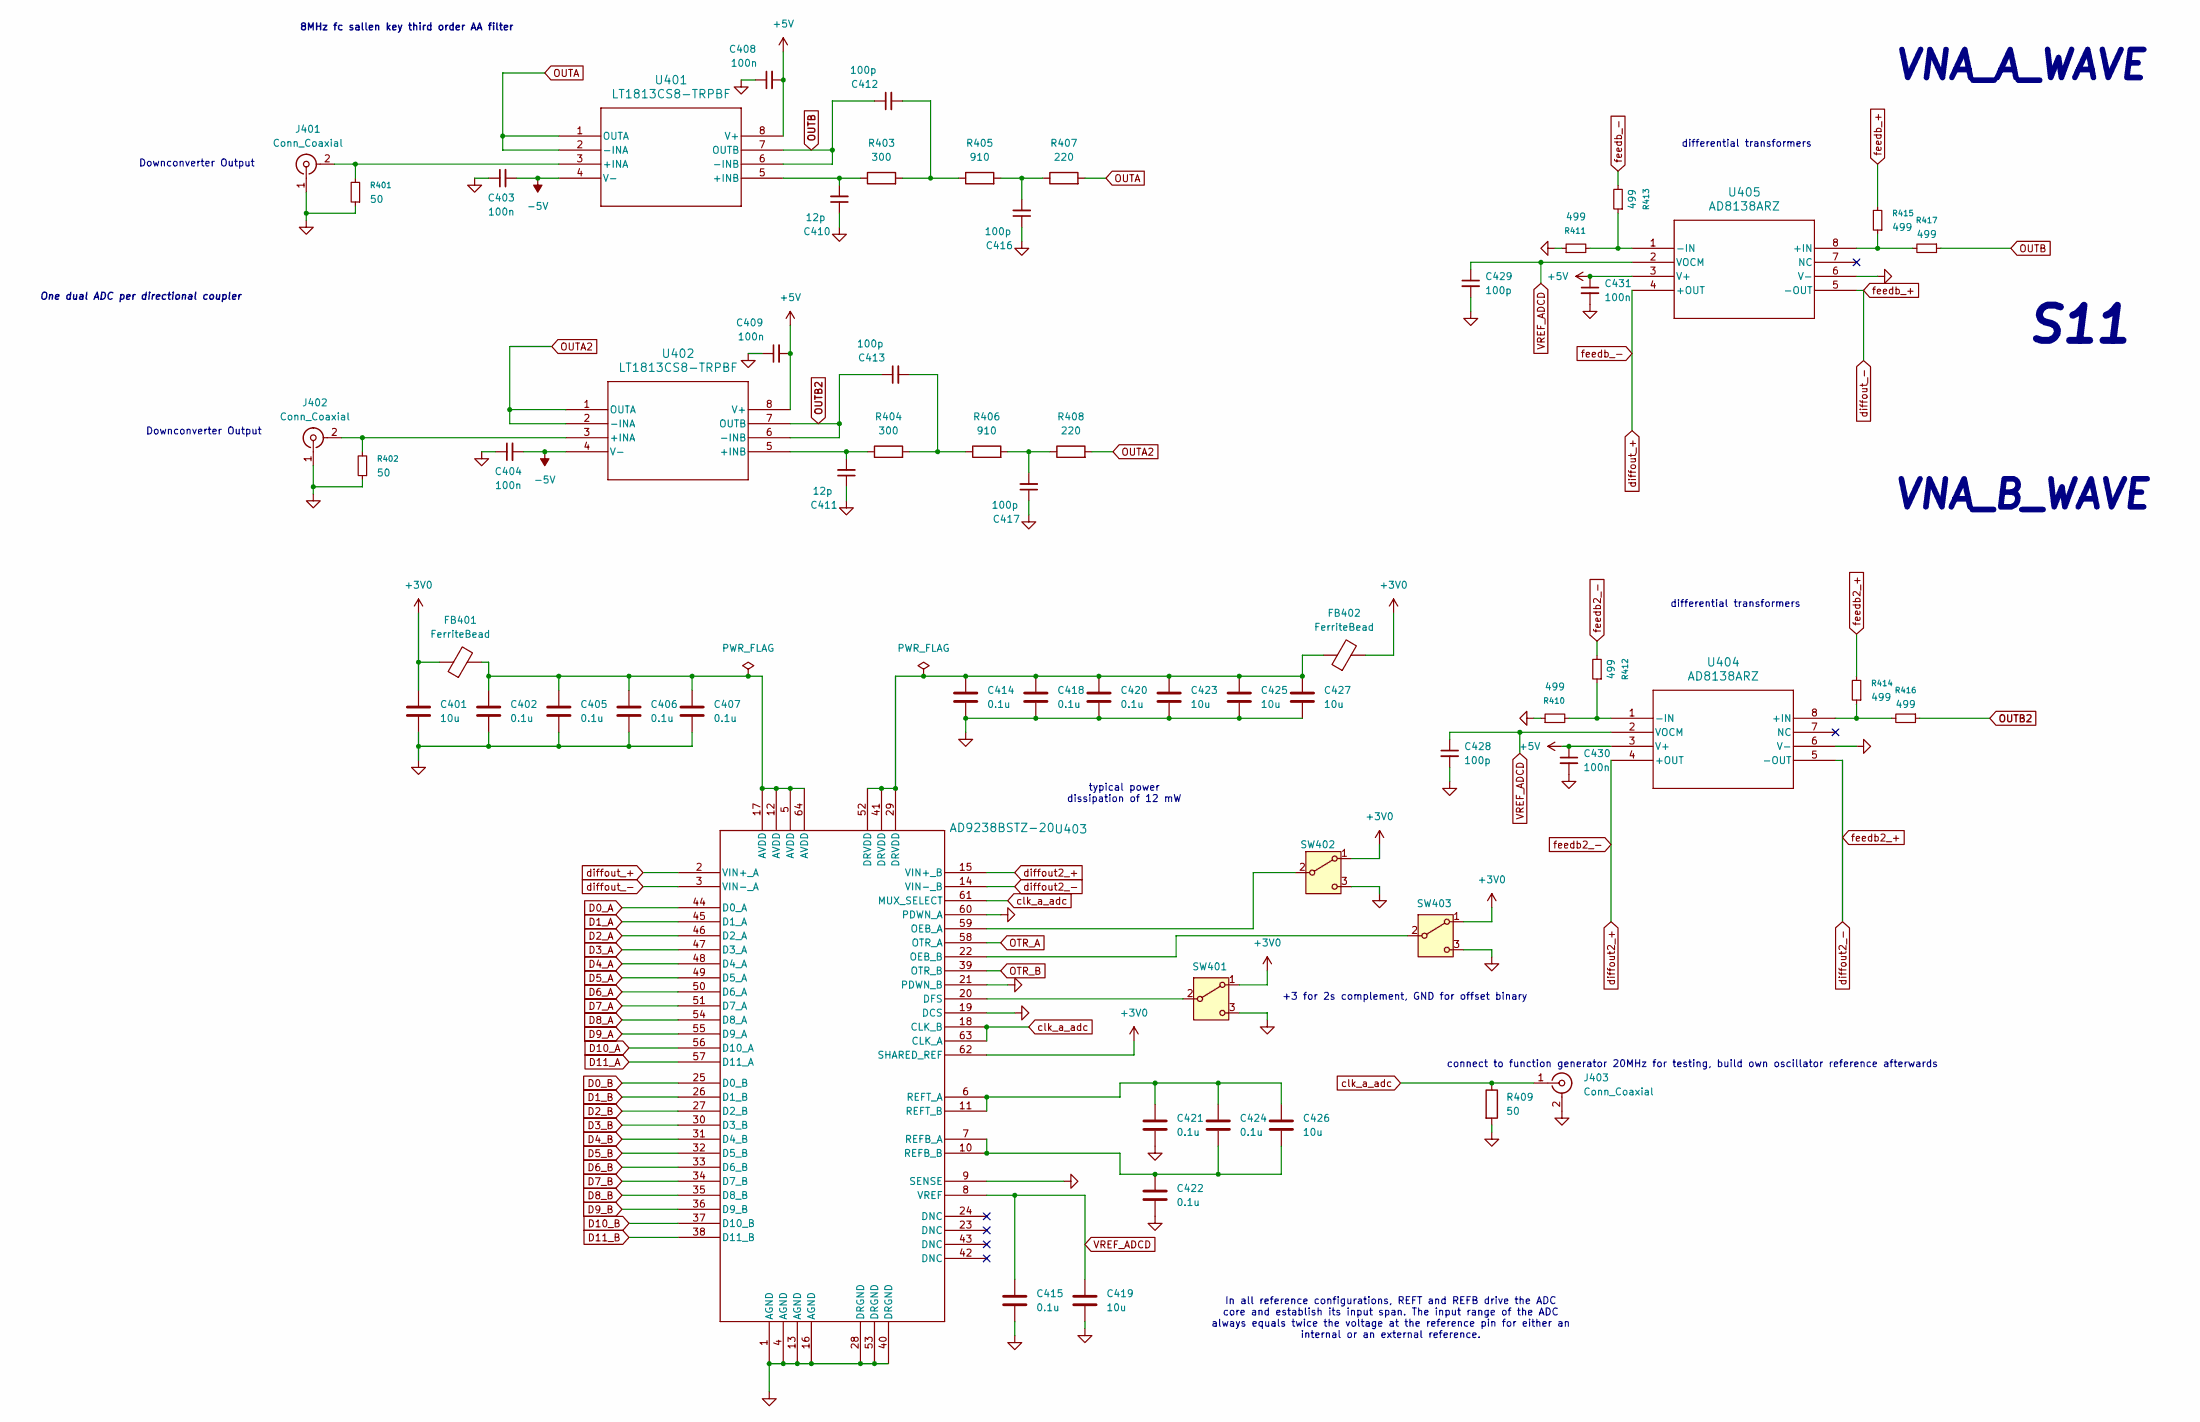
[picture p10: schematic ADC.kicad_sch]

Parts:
C401, C419, C423, C425, C426, C427: 10u; C_0603_1608Metric_Pad1.08x0.95mm_HandSolder
C402, C405, C406, C407, C414, C415, C418, C420, C421, C422, C424: 0.1u; C_0603_1608Metric_Pad1.08x0.95mm_HandSolder
C403, C404, C408, C409, C430, C431: 100n; C_0603_1608Metric_Pad1.08x0.95mm_HandSolder
C410, C411: 12p; C_0603_1608Metric_Pad1.08x0.95mm_HandSolder
C412, C413, C416, C417, C428, C429: 100p; C_0603_1608Metric_Pad1.08x0.95mm_HandSolder
FB401, FB402: FerriteBead; L_0603_1608Metric_Pad1.05x0.95mm_HandSolder
J401, J402, J403: Conn_Coaxial; SMA_Amphenol_901-144_Vertical
R401, R402, R409: 50; R_0603_1608Metric_Pad0.98x0.95mm_HandSolder
R403, R404: 300; R_0603_1608Metric_Pad0.98x0.95mm_HandSolder
R405, R406: 910; R_0603_1608Metric_Pad0.98x0.95mm_HandSolder
R407, R408: 220; R_0603_1608Metric_Pad0.98x0.95mm_HandSolder
R410, R411, R412, R413, R414, R415, R416, R417: 499; R_0603_1608Metric_Pad0.98x0.95mm_HandSolder
SW401, SW402, SW403: SW_SPDT; SW_Slide_SPDT_Straight_CK_OS102011MS2Q
U401, U402: LT1813CS8-TRPBF; SO-8_S_LIT-L
U403: AD9238BSTZ-20; ST_64_1_ADI
U404, U405: AD8138ARZ; R_8_ADI

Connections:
+3V0: C401.1, FB401.1, FB402.2, SW401.1 (A), SW402.1 (A), SW403.1 (A), U403.62 (SHARED_REF); also elsewhere on the board
+5V: C408.2, C409.2, C430.1, C431.1, U401.8 (V+), U402.8 (V+), U404.3 (V+), U405.3 (V+); also elsewhere on the board
-5V: C403.2, C404.2, U401.4 (V-), U402.4 (V-); also elsewhere on the board
D0_A: U403.44 (D0_A); also elsewhere on the board
D0_B: U403.25 (D0_B); also elsewhere on the board
D1_A: U403.45 (D1_A); also elsewhere on the board
D1_B: U403.26 (D1_B); also elsewhere on the board
D2_A: U403.46 (D2_A); also elsewhere on the board
D2_B: U403.27 (D2_B); also elsewhere on the board
D3_A: U403.47 (D3_A); also elsewhere on the board
D3_B: U403.30 (D3_B); also elsewhere on the board
D4_A: U403.48 (D4_A); also elsewhere on the board
D4_B: U403.31 (D4_B); also elsewhere on the board
D5_A: U403.49 (D5_A); also elsewhere on the board
D5_B: U403.32 (D5_B); also elsewhere on the board
D6_A: U403.50 (D6_A); also elsewhere on the board
D6_B: U403.33 (D6_B); also elsewhere on the board
D7_A: U403.51 (D7_A); also elsewhere on the board
D7_B: U403.34 (D7_B); also elsewhere on the board
D8_A: U403.54 (D8_A); also elsewhere on the board
D8_B: U403.35 (D8_B); also elsewhere on the board
D9_A: U403.55 (D9_A); also elsewhere on the board
D9_B: U403.36 (D9_B); also elsewhere on the board
D10_A: U403.56 (D10_A); also elsewhere on the board
D10_B: U403.37 (D10_B); also elsewhere on the board
D11_A: U403.57 (D11_A); also elsewhere on the board
D11_B: U403.38 (D11_B); also elsewhere on the board
GND: C401.2, C402.2, C403.1, C404.1, C405.2, C406.2, C407.2, C408.1, C409.1, C410.1, C411.1, C414.2, C415.2, C416.1, C417.1, C418.2, C419.2, C420.2, C421.2, C422.2, C423.2, C425.2, C427.2, C428.2, C429.2, C430.2, C431.2, J401.1 (In), J402.1 (In), J403.2 (Ext), R401.1, R402.1, R409.2, R410.1, R411.1, SW401.3 (C), SW402.3 (C), SW403.3 (C), U403.1 (AGND), U403.4 (AGND), U403.9 (SENSE), U403.13 (AGND), U403.16 (AGND), U403.19 (DCS), U403.21 (PDWN_B), U403.28 (DRGND), U403.40 (DRGND), U403.53 (DRGND), U403.60 (PDWN_A), U404.6 (V-), U405.6 (V-); also elsewhere on the board
unnamed: C402.1, C405.1, C406.1, C407.1, FB401.2, U403.5 (AVDD), U403.12 (AVDD), U403.17 (AVDD), U403.64 (AVDD)
unnamed: C412.2, R403.2, R405.1
unnamed: C413.2, R404.2, R406.1
unnamed: C414.1, C418.1, C420.1, C423.1, C425.1, C427.1, FB402.1, U403.29 (DRVDD), U403.41 (DRVDD), U403.52 (DRVDD)
unnamed: C416.2, R405.2, R407.1
unnamed: C417.2, R406.2, R408.1
unnamed: J401.2 (Ext), R401.2, U401.3 (+INA)
unnamed: J402.2 (Ext), R402.2, U402.3 (+INA)
unnamed: SW401.2 (B), U403.20 (DFS)
unnamed: SW402.2 (B), U403.59 (OEB_A)
unnamed: SW403.2 (B), U403.22 (OEB_B)
unnamed: C410.2, R403.1, U401.5 (+INB)
unnamed: C411.2, R404.1, U402.5 (+INB)
unnamed: C422.1, C424.2, C426.2, U403.7 (REFB_A), U403.10 (REFB_B)
unnamed: C421.1, C424.1, C426.1, U403.6 (REFT_A), U403.11 (REFT_B)
unnamed: R414.1, R416.2, U404.8 (+IN)
unnamed: R410.2, R412.1, U404.1 (-IN)
unnamed: R415.1, R417.2, U405.8 (+IN)
unnamed: R411.2, R413.1, U405.1 (-IN)
OTR_A: U403.58 (OTR_A); also elsewhere on the board
OTR_B: U403.39 (OTR_B); also elsewhere on the board
OUTA: R407.2, U401.1 (OUTA), U401.2 (-INA)
OUTA2: R408.2, U402.1 (OUTA), U402.2 (-INA)
OUTB: C412.1, R417.1, U401.6 (-INB), U401.7 (OUTB)
OUTB2: C413.1, R416.1, U402.6 (-INB), U402.7 (OUTB)
VREF_ADCD: C415.1, C419.1, C428.1, C429.1, U403.8 (VREF), U404.2 (VOCM), U405.2 (VOCM)
clk_a_adc: J403.1 (In), R409.1, U403.18 (CLK_B), U403.61 (MUX_SELECT), U403.63 (CLK_A)
diffout2_+: R412.2, U403.15 (VIN+_B), U404.4 (+OUT)
diffout2_-: R414.2, U403.14 (VIN-_B), U404.5 (-OUT)
diffout_+: R413.2, U403.2 (VIN+_A), U405.4 (+OUT)
diffout_-: R415.2, U403.3 (VIN-_A), U405.5 (-OUT)

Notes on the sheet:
VNA_B_WAVE
differential transformers
Downconverter Output
8MHz fc sallen key third order AA filter
connect to function generator 20MHz for testing, build own oscillator reference afterwards
+3 for 2s complement, GND for offset binary
S11
One dual ADC per directional coupler
typical power dissipation of 12 mW
In all reference configurations, REFT and REFB drive the ADC core and establish its input span. The input range of the ADC always equals twice the voltage at the reference pin for either an internal or an external reference.
VNA_A_WAVE

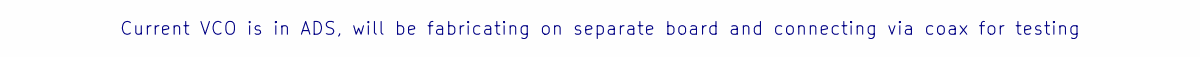
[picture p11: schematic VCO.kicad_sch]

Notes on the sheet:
Current VCO is in ADS, will be fabricating on separate board and connecting via coax for testing

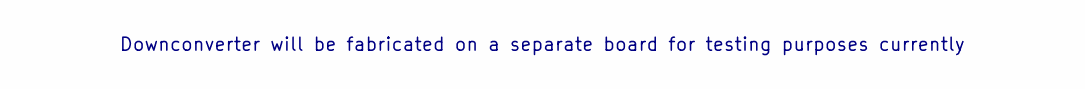
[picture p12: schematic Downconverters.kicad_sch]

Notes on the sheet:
Downconverter will be fabricated on a separate board for testing purposes currently

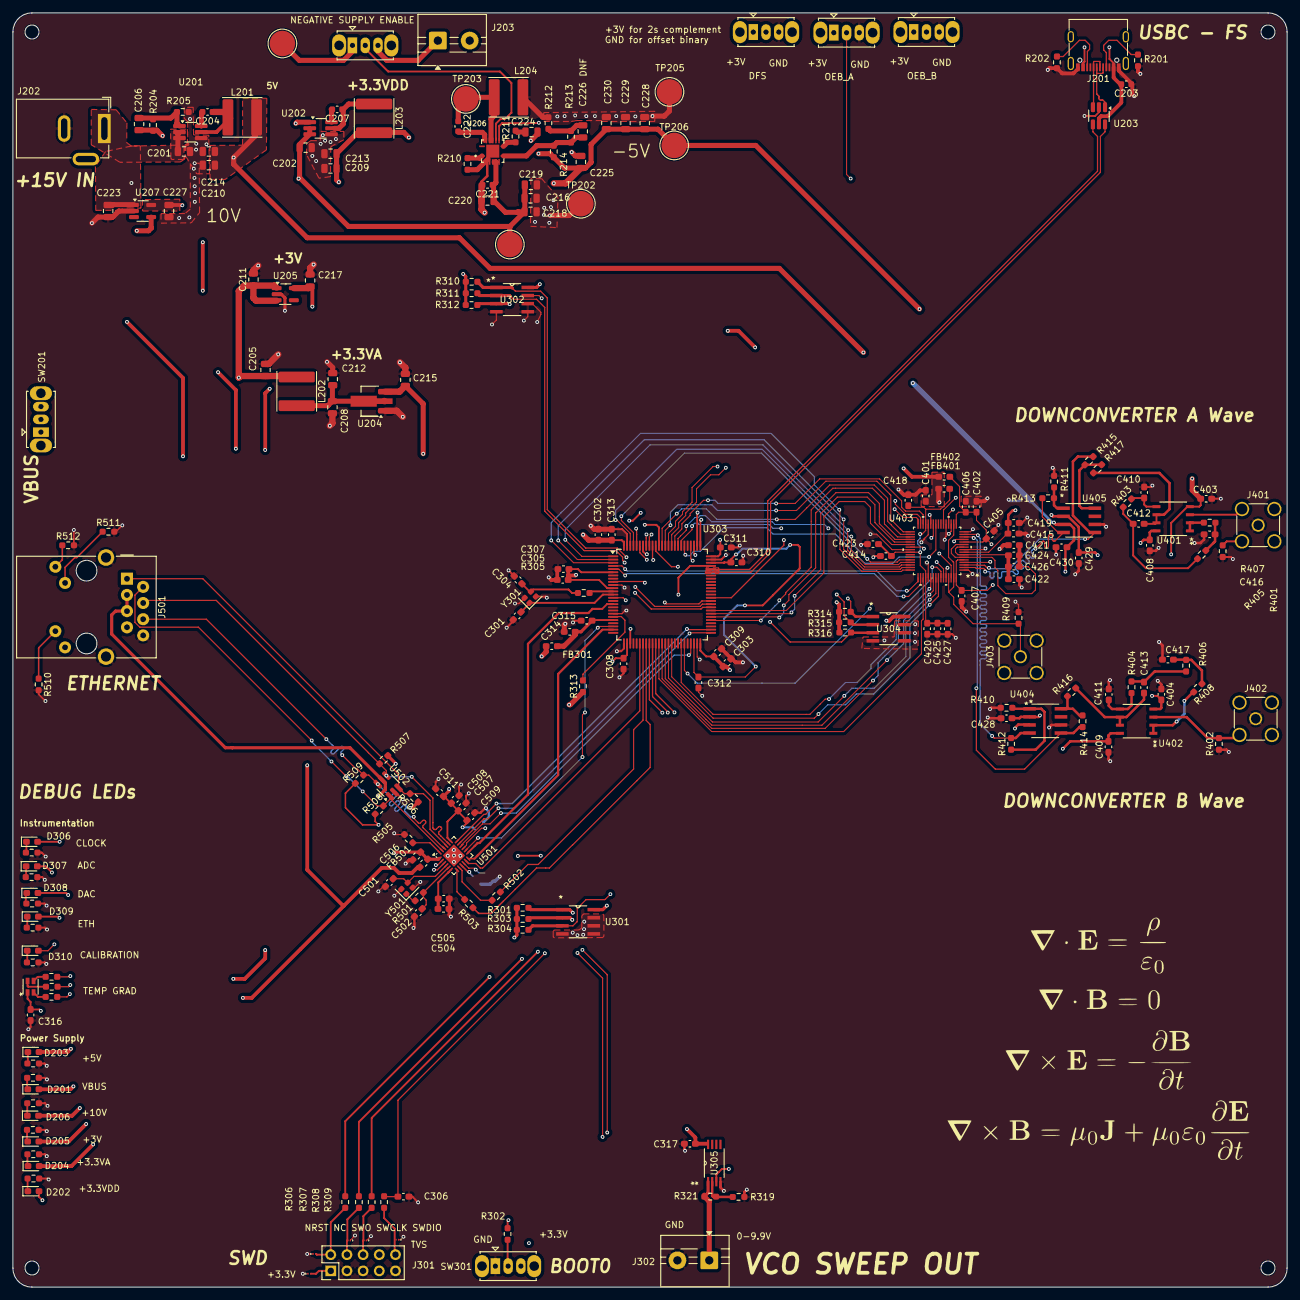
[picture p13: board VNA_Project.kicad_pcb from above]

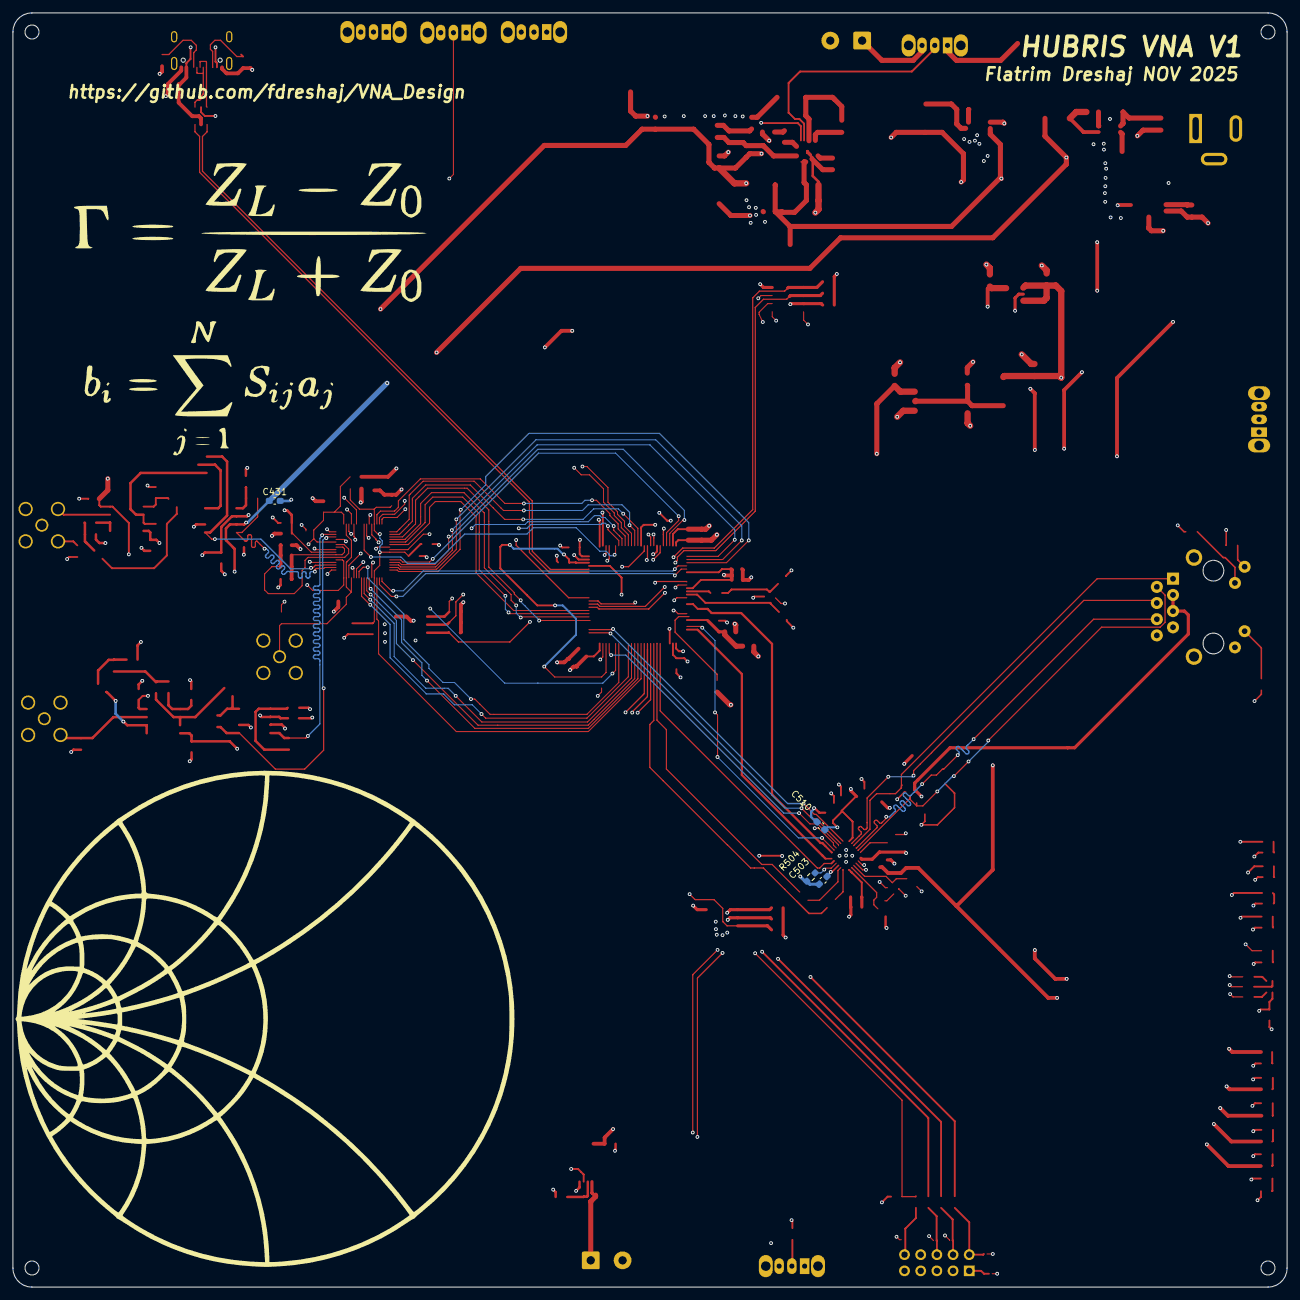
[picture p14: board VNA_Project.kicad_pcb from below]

Board: 6 copper layers, 200.0 x 200.0 mm, 230 parts (4 on the bottom side), 164 nets.

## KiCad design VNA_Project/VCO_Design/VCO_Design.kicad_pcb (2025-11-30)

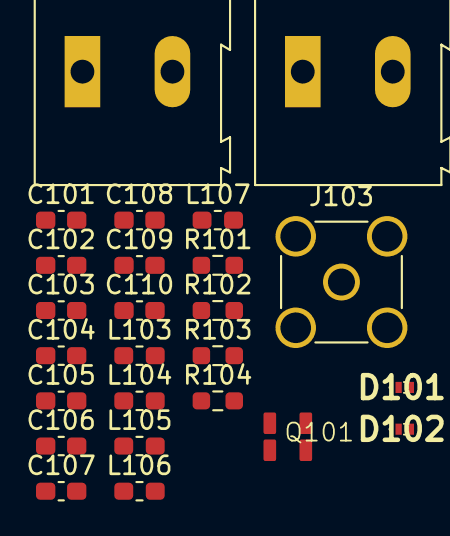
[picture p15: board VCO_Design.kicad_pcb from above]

Board: 2 copper layers, 25 parts (0 on the bottom side), 13 nets, no tracks yet.

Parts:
C101: 22p; C_0603_1608Metric_Pad1.08x0.95mm_HandSolder
C102, C103: 100n; C_0603_1608Metric_Pad1.08x0.95mm_HandSolder
C104, C105, C108, C109, C110: 22u; C_0603_1608Metric_Pad1.08x0.95mm_HandSolder
C106: 1.2p; C_0603_1608Metric_Pad1.08x0.95mm_HandSolder
C107: 1p; C_0603_1608Metric_Pad1.08x0.95mm_HandSolder
D101, D102: D_Capacitance; SMV1247
J101, J102: Screw_Terminal_01x02; TerminalBlock_Altech_AK300-2_P5.00mm
J103: Conn_Coaxial; SMA_Amphenol_901-144_Vertical
L103: 1.1n; L_0603_1608Metric_Pad1.05x0.95mm_HandSolder
L104, L105, L106, L107: 6.8n; L_0603_1608Metric_Pad1.05x0.95mm_HandSolder
Q101: BFP620; bfptransistor
R101: 5.6k; R_0603_1608Metric_Pad0.98x0.95mm_HandSolder
R102, R104: 0.3k; R_0603_1608Metric_Pad0.98x0.95mm_HandSolder
R103: 4.4k; R_0603_1608Metric_Pad0.98x0.95mm_HandSolder

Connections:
+5V: C102.2, C103.2, J102.1, R101.1, R102.1
GND: C101.2, C102.1, C103.1, C110.1, J101.2, J102.2, J103.2 (Ext), L103.1, L104.1, L106.1, R103.2, R104.2
unnamed: C105.2, C106.1, C107.2
unnamed: C107.1, C108.2
unnamed: C108.1, D101.2 (A), L104.2
unnamed: C109.2, D101.1 (K), L105.2
unnamed: C109.1, D102.2 (A), L106.2
unnamed: C110.2, D102.1 (K), L107.2
unnamed: C104.2, C106.2, J103.1 (In), L103.2
unnamed: C101.1, R101.2, R103.1
unnamed: C104.1, R102.2
unnamed: C105.1, R104.1
VCO: J101.1, L105.1, L107.1

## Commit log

2025-09-06 VCO and Power initial designs for 600-1200MHz
    VCO and Power initial designs for 600-1200MHz
    [Power.kicad_sch, VCO.kicad_sch, VNA_Project.kicad_pcb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]
2025-09-07 Started on MCU design, for sweeping
    [ADC.kicad_sch, DAC.kicad_sch, Directional_Coupler.kicad_sch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]
2025-09-07 Added ESP32 MCU design
    [MCU_vna.kicad_sch, Power.kicad_sch, VCO.kicad_sch]
2025-09-10 ADS schematic
    Added Keysight ADS schematic, will be working on getting a simulation done by this week for the VCO
    .
    [de_sim.cfg, hpeesofsim.cfg]
2025-10-07 VCO design
    VCO design initial prototype for 2.4-2.6 GHz with quite low phase noise of -123.6 dBc at 2.45
2025-10-08 Directional Coupler Schematic Design, 2.45 GHz
2025-10-08 Dir Coupler design 2.45 GHz
2025-10-14 directional coupler redesign
    dir coupler redesign
2025-10-15 Replace zip archive with extracted design files
    Removed the directional_coupler_design_git_v2.zip archive and added its extracted contents to version control. This change improves transparency and enables direct tracking of individual design files for the directional coupler project.
2025-10-25 Changing from a ESP32 S3 to STM32 H7 high performance MCU for USB HS and ETH capabilities
    Changing from a ESP32 S3 to STM32 H7 high performance MCU for USB HS and ETH capabilities
    [Downconverters.kicad_sch, Ethernet.kicad_sch, Filters.kicad_sch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]
2025-10-25 minor changes
    minor changes
    [MCU_vna.kicad_sch, VNA_Project.kicad_sch]
2025-10-29 minor changes eth
    minor changes eth
    [Ethernet.kicad_sch, MCU_vna.kicad_sch]
2025-10-29 eth
    eth
    [Ethernet.kicad_sch]
2025-10-29 Eth done
    Eth done
    [Ethernet.kicad_sch, MCU_vna.kicad_sch, Power.kicad_sch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]
2025-10-29 ADC initial
    ADC initial
    [ADC.kicad_sch]
2025-10-29 ADC AA filter
    ADC AA Filter
    [ADC.kicad_sch]
2025-11-02 adc
    adc
    [ADC.kicad_sch]
2025-11-03 DAC
    DAC
    [MCU_vna.kicad_sch, Power.kicad_sch, VNA_Project.kicad_sch]
2025-11-03 finishing up front end
    refining Non RF front end
    [ADC.kicad_sch, Directional_Coupler.kicad_sch, Downconverters.kicad_sch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]
2025-11-03 AA filtering
    redoing AA filtering
    [ADC.kicad_sch, Ethernet.kicad_sch, MCU_vna.kicad_sch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]
2025-11-03 VNA V1
    FRONT END FIRST PROTOTYPE SCHEMATIC DONE
    [ADC.kicad_sch, MCU_vna.kicad_sch, Power.kicad_sch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]
2025-11-03 footprints + initial layout shape
    footprints + initial layout shape
    [ADC.kicad_sch, Directional_Coupler.kicad_sch, Ethernet.kicad_sch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]
2025-11-04 Layout
    Layout
    [Ethernet.kicad_sch, MCU_vna.kicad_sch, VNA_Project.kicad_pcb]
2025-11-10 ethernet Layout
    Ethernet Layout
    [Ethernet.kicad_sch, VNA_Project.kicad_pcb]
2025-11-11 Clarify KiCad file updates and layout tasks
    Updated README to clarify KiCad file status and remaining work on the motherboard layout.
2025-11-28 finished Routing
    finished Routing
    [VNA_Project.kicad_pcb]
2025-11-28 clearance changed
    clearance changed
    [VNA_Project.kicad_pcb]
2025-11-28 DRC silkscreen
    fixed DRC and silkscreen
    [MCU_vna.kicad_sch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]
2025-11-29 GRB BOM
    GRB BOM
    [Power.kicad_sch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]
2025-11-30 VCO Design
    VCO Design
    [VCO_Design.kicad_pcb, VCO_Design.kicad_sch]
2025-12-01 Update VCO_Design.kicad_sch
    vco finished,
    [VCO_Design.kicad_sch]
2025-12-01 gerb
    gerbers
    [VNA_Project-B_Cu.gbr, VNA_Project-B_Mask.gbr, VNA_Project-B_Paste.gbr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]
